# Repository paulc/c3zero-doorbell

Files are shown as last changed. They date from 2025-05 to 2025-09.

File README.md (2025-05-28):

ESP32C3-Zero Doorbell Ring Detector (using Hall effect current sensor)

To plot raw samples (set SAMPLES & SAMPLE_RATE in examples/sample_timer.rs)

```
cargo run --release --example sample_timer | uv run --with matplotlib python plot.py
cargo run --release --example sample_continuous | uv run --with matplotlib python plot.py
```

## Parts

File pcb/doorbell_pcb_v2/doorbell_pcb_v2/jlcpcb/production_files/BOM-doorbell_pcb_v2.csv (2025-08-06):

Comment | Designator | Footprint | LCSC | Quantity
DF06S | D1 | Diode_Bridge_OnSemi_SDIP-4L | C105154 | 1
470nF | C4 | C_0805_2012Metric_Pad1.18x1.45mm_HandSolder | C13967 | 1
470R | R1,R2,R3 | R_0805_2012Metric_Pad1.20x1.40mm_HandSolder | C17710 | 3
MST22D18G2 125 | SW1 | SW-SMD_MST22D18G2 | C2906280 | 1
ACS712xLCTR-05B | U1 | SOIC-8_3.9x4.9mm_P1.27mm | C44471 | 1
1nF | C1 | C_0805_2012Metric_Pad1.18x1.45mm_HandSolder | C46653 | 1
100nF | C2,C5 | C_0805_2012Metric_Pad1.18x1.45mm_HandSolder | C49678 | 2
470uF | C3 | CP_Elec_10x10.5 | C5162362 | 1
LM78M05_TO252 | U2 | TO-252-2 | C58069 | 1
LED | D2 | LED_0805_2012Metric_Pad1.15x1.40mm_HandSolder | C84256 | 1
B5819 | D3 | D_SOD-123 | C8598 | 1
Conn_01x03_Pin |  | PinHeader_1x03_P2.54mm_Vertical |  | 0
TestPoint (ADC In) | TP1 | TestPoint_THTPad_1.5x1.5mm_Drill0.7mm |  | 1

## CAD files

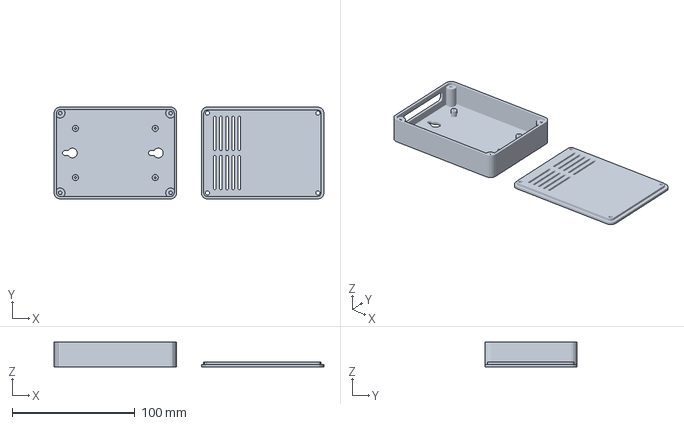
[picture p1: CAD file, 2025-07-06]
case/doorbell_case.3mf
220.0 x 75.0 x 20.0 mm

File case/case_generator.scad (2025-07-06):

// Box Parameters
box_length = 100;
box_width = 75;
box_height = 20;
wall_thickness = 2;
corner_radius = 5;
lid_clearance = 0.2;
lid_height = 2;

// Screw pillar parameters
screw_hole_diameter = 3;
pillar_diameter = 8;
pillar_height = box_height - wall_thickness;

// Mounting hole parameters
mounting_holes = true;
mounting_hole_offset = 0.15;
mounting_top_diameter = 5;
mounting_screw_diameter = 2.5;

// PCB mount parameters
pcb_pillars = true;
pcb_width = 40;     // Between mounting holes
pcb_length = 60;    // Between mounting holes
pcb_pillar_height = 5;
pcb_pillar_diameter = 5;
pcb_hole_diameter = 1.5;

// Cutouts
front_cutout = false;
front_cutout_size = [5,5];
front_cutout_offset = [0,0];
front_cutout_radius = 2.5;

back_cutout = false;
back_cutout_size = [5,5];
back_cutout_offset = [0,0];
back_cutout_radius = 2.5;

left_cutout = false;
left_cutout_size = [5,5];
left_cutout_offset = [0,0];
left_cutout_radius = 2.5;

right_cutout = false;
right_cutout_size = [5,5];
right_cutout_offset = [0,0];
right_cutout_radius = 2.5;

ventilation_holes = false;
num_ventilation_holes = 5;

// Main box with flat top and bottom and screw pillars
module rounded_box(length, width, height, radius, thickness) {
    difference() {
        union() {
            difference() {
                // Outer shape with rounded sides but flat top/bottom
                linear_extrude(height)
                offset(r = radius) offset(delta = -radius)
                square([length, width], center = false);
         
                // Inner cutout
                translate([thickness, thickness, thickness])
                linear_extrude(height - thickness + 0.1)
                offset(r = max(radius - thickness, 0)) 
                offset(delta = -(max(radius - thickness, 0)))
                square([length - thickness*2, width - thickness*2], center = false);
                
                
            }
            // Add four screw pillars
            for (pos = [
                [radius, radius, 0],
                [length - radius, radius, 0],
                [radius, width - radius, 0],
                [length - radius, width - radius, 0]
            ]) {
                translate(pos)
                cylinder(h = pillar_height, d = pillar_diameter, $fn = 20);
            }
            // PCB Pillars
            if (pcb_pillars) {
                pcb_pillars();  
            }
        }
        // Screw holes through pillars
        for (pos = [
            [radius, radius, wall_thickness],
            [length - radius, radius, wall_thickness],
            [radius, width - radius, wall_thickness],
            [length - radius, width - radius, wall_thickness]
        ]) {
            translate(pos)
            cylinder(h = pillar_height + 0.1, d = screw_hole_diameter, $fn = 20);
        }

        // Mounting holes
        if (mounting_holes) {
            mounting_hole(box_length * mounting_hole_offset, box_width/2);
            mounting_hole(box_length * (1 - mounting_hole_offset), box_width/2);
        }
        
        // Cutout
        if (front_cutout) {
                side_cutout("front", 
                    size = front_cutout_size, 
                    offset = front_cutout_offset,
                    radius = front_cutout_radius);
        } 
        if (back_cutout) {
                side_cutout("back", 
                    size = back_cutout_size, 
                    offset = back_cutout_offset,
                    radius = back_cutout_radius);
        } 
        if (left_cutout) {
                side_cutout("left", 
                    size = left_cutout_size, 
                    offset = left_cutout_offset,
                    radius = left_cutout_radius);
        } 
        if (right_cutout) {
                side_cutout("right", 
                    size = right_cutout_size, 
                    offset = right_cutout_offset,
                    radius = right_cutout_radius);
        } 
    }
}

module side_cutout(
    side,               // "front", "back", "left", "right"
    size = [5,5],       // width, height
    offset = [0,0],     // left/right, up/down
    radius = 0
) {
    width = size[0];
    height = size[1];
    
    // Make sure radius is less than width/height
    radius = (radius < min(width/2,height/2)) ? radius : min(width/2,height/2) - 0.01;
    
    lr = offset[0];
    ud = offset[1];
    
    if (side == "front") {
        translate([0 - 0.01, box_width/2 - width / 2 + lr, box_height/2 - height/2 + ud])
            rotate([90,0,90])
            linear_extrude(height = wall_thickness + 0.02, $fn = 20)
                offset (r = radius) offset(delta = -radius)
                square([width,height]);
    } else if (side == "back") {
         translate([box_length - wall_thickness - 0.01, box_width/2 - width/2 + lr, box_height/2 - height/2 + ud])
            rotate([90,0,90])
            linear_extrude(height = wall_thickness + 0.02, $fn = 20)
                offset (r = radius) offset(delta = -radius)
                square([width,height]);   
    } else if (side == "left") {
         translate([box_length/2 - width/2 + lr, wall_thickness + 0.01, box_height/2 - height/2 + ud])
            rotate([90,0,0])
            linear_extrude(height = wall_thickness + 0.02, $fn = 20)
                offset (r = radius) offset(delta = -radius)
                square([width,height]);   
    } else if (side == "right") {
         translate([box_length/2 - width/2 + lr, box_width + 0.01, box_height/2 - height/2 + ud])
            rotate([90,0,0])
            linear_extrude(height = wall_thickness + 0.02, $fn = 20)
                offset (r = radius) offset(delta = -radius)
                square([width,height]);   
    }
}


module pcb_pillars() {
    y0 = (box_width - pcb_width) / 2;
    y1 = y0 + pcb_width;
    x0 = (box_length - pcb_length) / 2;
    x1 = x0 + pcb_length;
    
    for (pos = [[x0,y0,0],[x0,y1,0],[x1,y0,0],[x1,y1,0]]) {
        translate(pos) 
        difference() {
            cylinder(h = pcb_pillar_height + wall_thickness, d = pcb_pillar_diameter, $fn = 20);
            translate([0,0,wall_thickness])
                cylinder(h = pcb_pillar_height + 0.01, d = pcb_hole_diameter, $fn = 20);
        }
    }
}

module mounting_hole(x,y) {
        // We add a very small +/- z delta to make preview render clearer
        translate([x,y,-0.01])
            linear_extrude(wall_thickness + 0.02)
                rotate([0,0,180])
                union() {
                    circle(d = mounting_top_diameter, $fn=20);
                    translate([mounting_top_diameter/2,0,0])
                        offset(r = mounting_screw_diameter/2, $fn = 20) 
                            square([mounting_screw_diameter,0.1], center= true);
                }
}

// Lid with flat bottom and screw holes
module rounded_lid(length, width, height, radius, thickness) {
    difference() {
        union() {
            // Main lid plate with flat bottom
            linear_extrude(height)
            offset(r = radius) offset(delta = -radius)
            square([length, width], center = false);
            
            // Lip that fits inside the box
            translate([thickness, thickness, height])
            linear_extrude(height)
            offset(r = max(radius - thickness - lid_clearance, 0))
            offset(delta = -(max(radius - thickness - lid_clearance, 0)))
            square([
                length - thickness*2 - lid_clearance*2, 
                width - thickness*2 - lid_clearance*2
            ], center = false);
        }
        
        // Screw holes in lid
        for (pos = [
            [radius, radius, 0],
            [length - radius, radius, 0],
            [radius, width - radius, 0],
            [length - radius, width - radius, 0]
        ]) {
            translate(pos)
            cylinder(h = height*2, d = screw_hole_diameter + 0.5, $fn = 10); // Slightly larger for clearance
        }
        
        // Ventilation holes
        if (ventilation_holes) {
            for (i = [0:num_ventilation_holes-1] ) {
                translate([length * (0.1 + i/20), width * 0.1, -0.01])
                    linear_extrude(height * 2 + 0.02)
                        offset(r = thickness/2, $fn = 10) offset(delta = -thickness/2)
                        square([height + 0.01, width * 0.375]);
                translate([length * (0.1 + i/20), width * 0.525, -0.01])
                    linear_extrude(height * 2 + 0.02)
                        offset(r = thickness/2, $fn = 10) offset(delta = -thickness/2)
                        square([height + 0.01, width * 0.375]);
            }    
        }
    }
}

// Create the box
rounded_box(box_length, box_width, box_height, corner_radius, wall_thickness);

// Create the lid (positioned next to the box for printing)
translate([box_length + 20, 0, 0])
    rounded_lid(box_length, box_width, lid_height, corner_radius, wall_thickness);

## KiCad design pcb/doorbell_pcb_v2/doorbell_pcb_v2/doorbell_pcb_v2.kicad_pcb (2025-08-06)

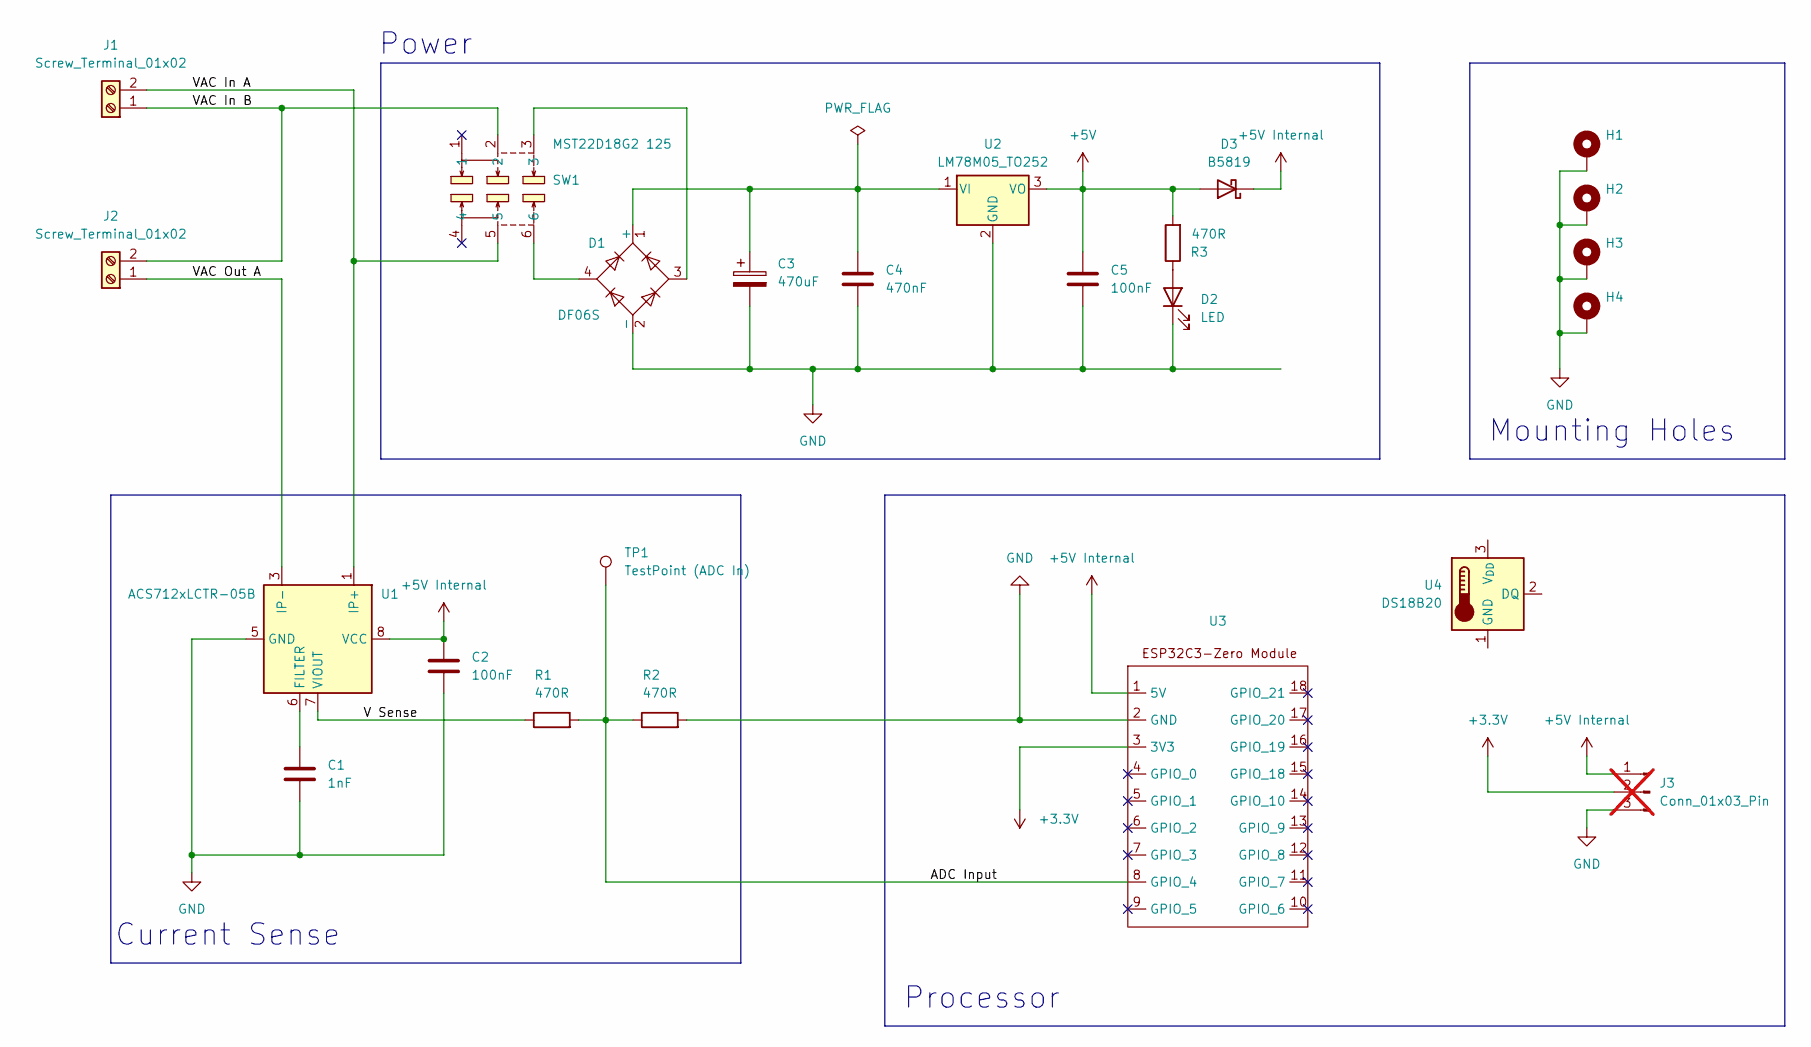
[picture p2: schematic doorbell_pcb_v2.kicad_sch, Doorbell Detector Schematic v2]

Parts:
C1: 1nF; C_0805_2012Metric_Pad1.18x1.45mm_HandSolder; LCSC C46653
C2, C5: 100nF; C_0805_2012Metric_Pad1.18x1.45mm_HandSolder; LCSC C49678
C3: 470uF; CP_Elec_10x10.5; LCSC C5162362
C4: 470nF; C_0805_2012Metric_Pad1.18x1.45mm_HandSolder; LCSC C13967
D1: DF06S; Diode_Bridge_OnSemi_SDIP-4L; LCSC C105154
D2: LED; LED_0805_2012Metric_Pad1.15x1.40mm_HandSolder; JLCPCB C84256
D3: B5819; D_SOD-123; LCSC C8598
H1, H2, H3, H4: MountingHole_Pad; MountingHole_2.2mm_M2_Pad
J1: Screw_Terminal_01x02; CONN-TH_P5.00_KF301-5.0-2P; LCSC C474881
J2: Screw_Terminal_01x02; CONN-TH_P5.00_KF301-5.0-2P; JLC C474881
J3: Conn_01x03_Pin; PinHeader_1x03_P2.54mm_Vertical; not fitted
R1, R2, R3: 470R; R_0805_2012Metric_Pad1.20x1.40mm_HandSolder; LCSC C17710
SW1: MST22D18G2 125; SW-SMD_MST22D18G2; LCSC Part C2906280
TP1: TestPoint (ADC In); TestPoint_THTPad_1.5x1.5mm_Drill0.7mm
U1: ACS712xLCTR-05B; SOIC-8_3.9x4.9mm_P1.27mm; LCSC C44471
U2: LM78M05_TO252; TO-252-2; LCSC C58069
U3: esp32c3-zero
U4: DS18B20; TO-92

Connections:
+3.3V: J3.2, U3.3 (3V3)
+5V: C5.1, D3.2 (A), R3.2, U2.3 (VO)
+5V Internal: C2.1, D3.1 (K), J3.1, U1.8 (VCC), U3.1 (5V)
/ADC Input: R1.2, R2.1, TP1.1, U3.8 (GPIO_4)
/V Sense: R1.1, U1.7 (VIOUT)
/VAC In A: J1.2, SW1.5, U1.1 (IP+), U1.2 (IP+)
/VAC In B: J1.1, J2.2, SW1.2
/VAC Out A: J2.1, U1.3 (IP-), U1.4 (IP-)
GND: C1.2, C2.2, C3.2, C4.2, C5.2, D1.2 (-), D2.1 (K), H1.1, H2.1, H3.1, H4.1, J3.3, R2.2, U1.5 (GND), U2.2 (GND), U3.2 (GND)
unnamed: C3.1, C4.1, D1.1 (+), U2.1 (VI)
unnamed: D1.3, SW1.3
unnamed: D1.4, SW1.6
unnamed: D2.2 (A), R3.1
unnamed: C1.1, U1.6 (FILTER)

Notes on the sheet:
Processor
Current Sense
Mounting Holes
Power

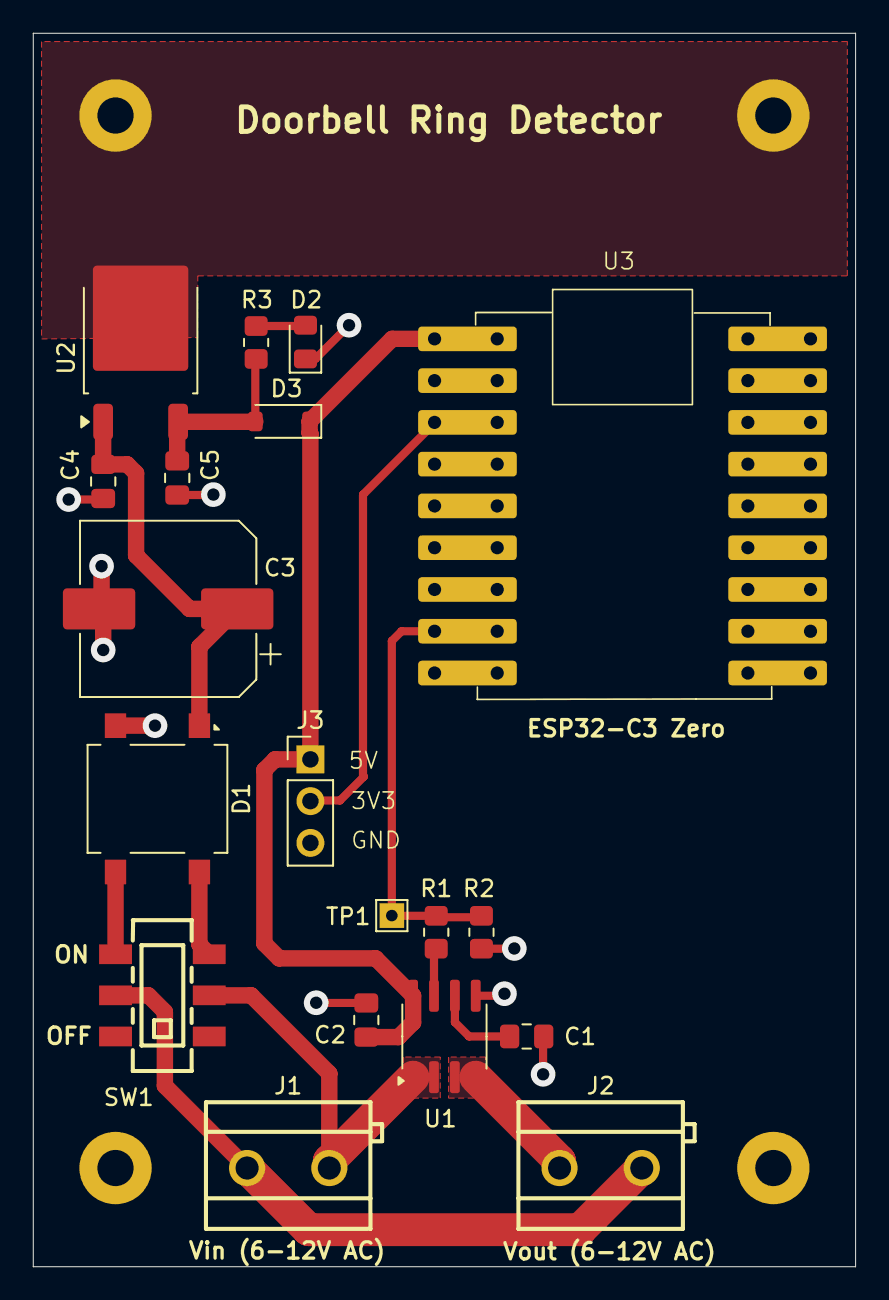
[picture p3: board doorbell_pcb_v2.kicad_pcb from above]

Board: 2 copper layers, 50.0 x 75.0 mm, 23 parts (0 on the bottom side), 14 nets.

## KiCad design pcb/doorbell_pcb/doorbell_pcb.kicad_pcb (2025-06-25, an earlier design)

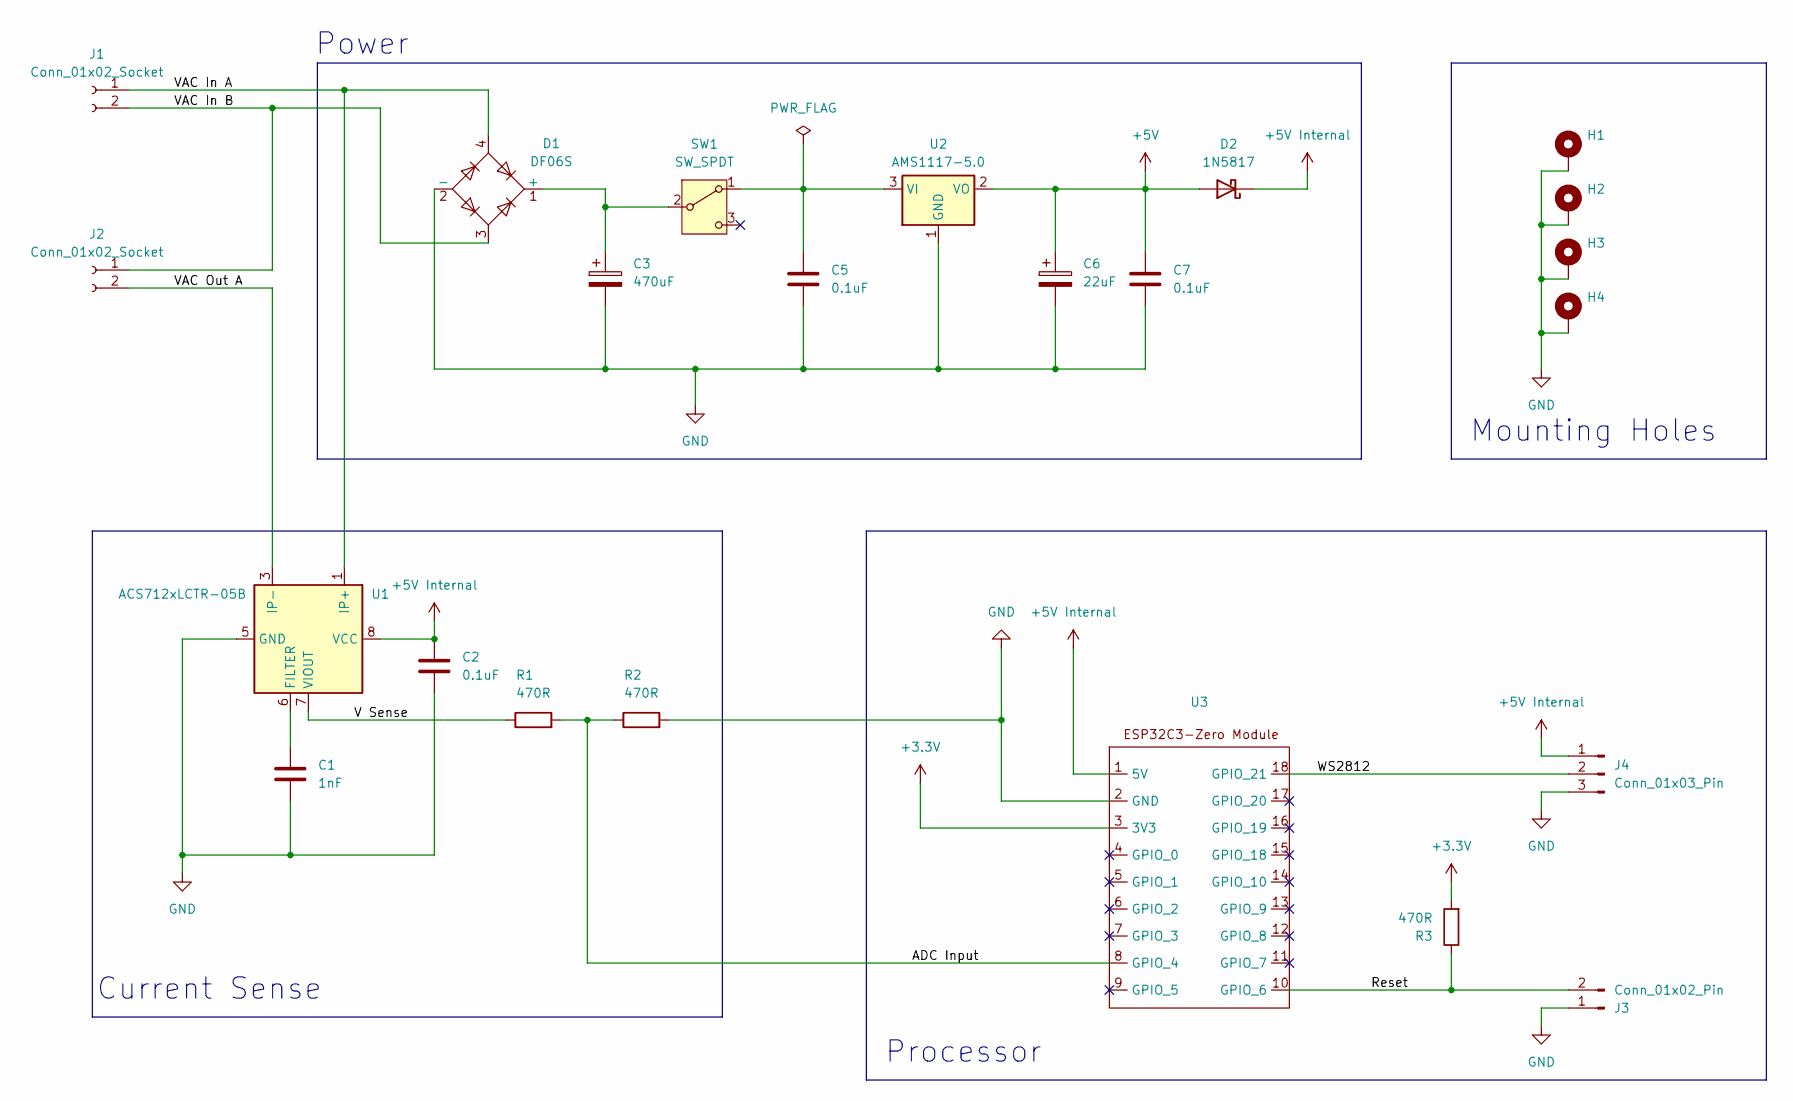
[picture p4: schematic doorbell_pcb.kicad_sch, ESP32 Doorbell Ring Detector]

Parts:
C1: 1nF; C_0805_2012Metric
C2, C5, C7: 0.1uF; C_0805_2012Metric
C3: 470uF; CP_Elec_10x10.5
C6: 22uF; CP_Elec_10x10.5
D1: DF06S; Diode_Bridge_OnSemi_SDIP-4L
D2: 1N5817; D_SOD-323
H1, H2, H3, H4: MountingHole_Pad; MountingHole_2.2mm_M2_Pad
J1, J2: Conn_01x02_Socket; TerminalBlock_Phoenix_MPT-0,5-2-2.54_1x02_P2.54mm_Horizontal
J3: Conn_01x02_Pin; JST_EH_B2B-EH-A_1x02_P2.50mm_Vertical
J4: Conn_01x03_Pin; JST_EH_B3B-EH-A_1x03_P2.50mm_Vertical
R1, R2, R3: 470R; R_0805_2012Metric
SW1: SW_SPDT; SW_SPDT_CK_JS102011SAQN
U1: ACS712xLCTR-05B; SOIC-8_3.9x4.9mm_P1.27mm
U2: AMS1117-5.0; SOT-223-3_TabPin2
U3: esp32c3-zero

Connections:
+3.3V: R3.2, U3.3 (3V3)
+5V: C6.1, C7.1, D2.2 (A), U2.2 (VO)
+5V Internal: C2.1, D2.1 (K), J4.1, U1.8 (VCC), U3.1 (5V)
/ADC Input: R1.2, R2.1, U3.8 (GPIO_4)
/Reset: J3.2, R3.1, U3.10 (GPIO_6)
/V Sense: R1.1, U1.7 (VIOUT)
/VAC In A: D1.4, J1.1, U1.1 (IP+), U1.2 (IP+)
/VAC In B: D1.3, J1.2, J2.1
/VAC Out A: J2.2, U1.3 (IP-), U1.4 (IP-)
/WS2812: J4.2, U3.18 (GPIO_21)
GND: C1.2, C2.2, C3.2, C5.2, C6.2, C7.2, D1.2 (-), H1.1, H2.1, H3.1, H4.1, J3.1, J4.3, R2.2, U1.5 (GND), U2.1 (GND), U3.2 (GND)
unnamed: C3.1, D1.1 (+), SW1.2 (B)
unnamed: C5.1, SW1.1 (A), U2.3 (VI)
unnamed: C1.1, U1.6 (FILTER)

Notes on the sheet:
Current Sense
Power
Mounting Holes
Processor

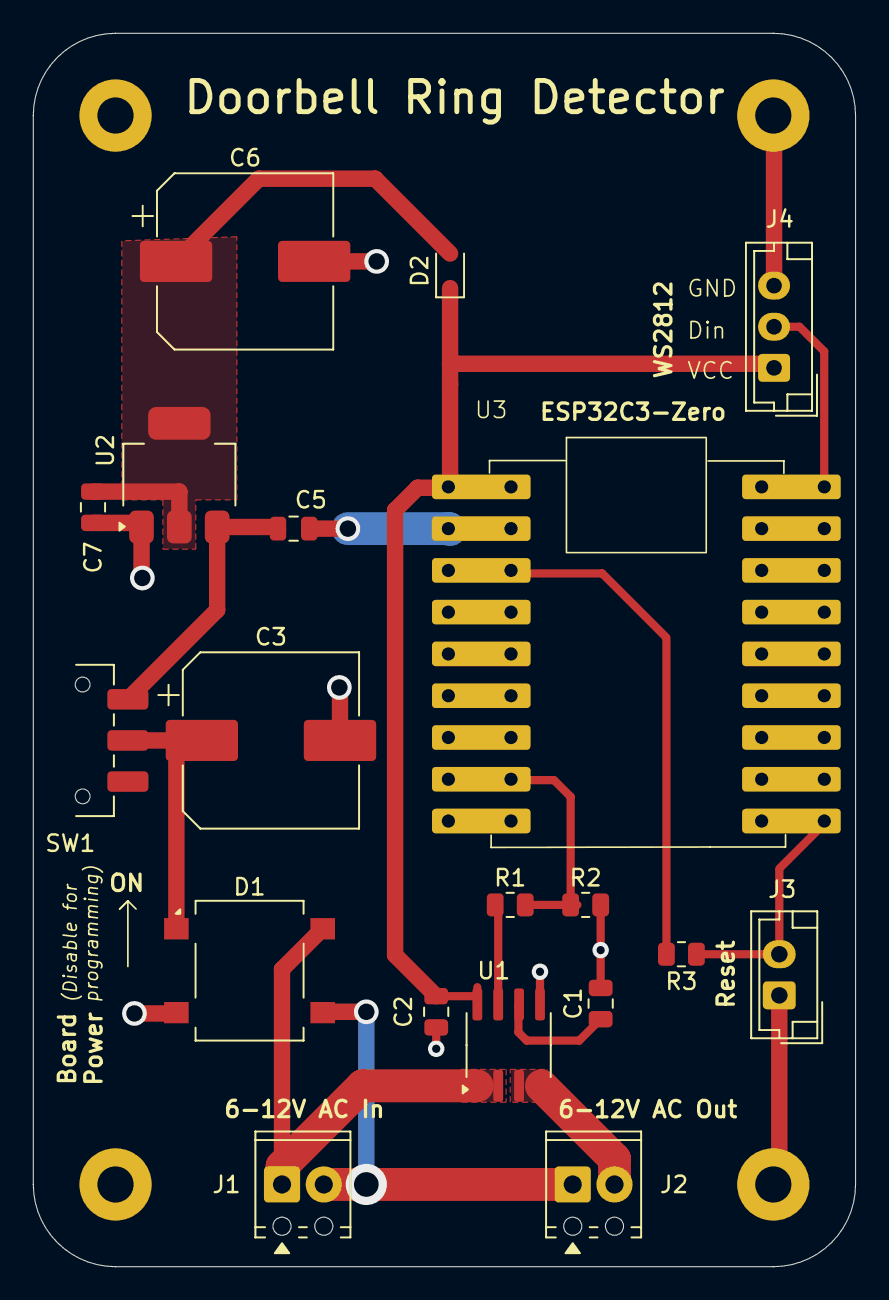
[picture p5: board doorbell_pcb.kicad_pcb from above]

Board: 2 copper layers, 50.0 x 75.0 mm, 23 parts (0 on the bottom side), 14 nets.

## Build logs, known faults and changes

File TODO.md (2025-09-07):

[ ] Convert MQTT/Pushover/Wifi forms to application/json
[ ] Add config test to MQTT/Pushover forms
[ ] Sync mqtt alarm code with doorbell
[ ] Add config option for LED flash
[ ] MQTT alarm PWM ringer
[ ] Add config option for ADC gain
[ ] Move doorbell/alarm to src/bin
[ ] Add temperature sensor?
[ ] Convert status messages to JSON

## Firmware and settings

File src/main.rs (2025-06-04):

use esp_idf_hal::gpio::{OutputPin, PinDriver};
use esp_idf_hal::peripherals::Peripherals;
use esp_idf_hal::task::watchdog::{TWDTConfig, TWDTDriver};
use esp_idf_svc::eventloop::EspSystemEventLoop;
use esp_idf_svc::nvs::EspDefaultNvsPartition;
use esp_idf_svc::wifi::EspWifi;

use std::sync::mpsc;
use std::thread;
use std::time::Duration;

use doorbell::httpd;
use doorbell::nvs;
use doorbell::rgb;
use doorbell::wifi;
use doorbell::ws2812;

mod adc;
mod alert;
mod stats;

fn main() -> anyhow::Result<()> {
    esp_idf_hal::sys::link_patches();

    // Bind the log crate to the ESP Logging facilities
    esp_idf_svc::log::EspLogger::initialize_default();
    log::info!("Started...");

    // Initialise peripherals
    let peripherals = Peripherals::take()?;
    let sys_loop = EspSystemEventLoop::take()?;
    let nvs_default_partition = EspDefaultNvsPartition::take()?;

    // Hardware Watchdog
    let twdt_config = TWDTConfig {
        duration: Duration::from_secs(2),
        panic_on_trigger: true,
        subscribed_idle_tasks: enumset::enum_set!(esp_idf_hal::cpu::Core::Core0),
    };
    let mut twdt_driver = TWDTDriver::new(peripherals.twdt, &twdt_config)?;

    // Status display (C3-Zero onboard WS2812 LED pin = GPIO10)
    let ws2812 = peripherals.pins.gpio10.downgrade_output();
    let channel = peripherals.rmt.channel0;
    let mut status = ws2812::Ws2812RmtSingle::new(ws2812, channel, rgb::RgbLayout::Rgb)?;
    status.set(rgb::OFF)?;

    // Ring led
    let mut ring_led = PinDriver::output(peripherals.pins.gpio6)?;
    ring_led.set_high()?;

    // Initislise NVStore
    nvs::NVStore::init(nvs_default_partition.clone(), "DOORBELL")?;

    // Initialise WiFi
    let mut wifi: EspWifi<'_> = EspWifi::new(
        peripherals.modem,
        sys_loop.clone(),
        Some(nvs_default_partition.clone()),
    )?;
    wifi::wifi_init(&mut wifi)?;

    // Initial scan
    wifi::wifi_scan(&mut wifi)?;

    let mut wifi_config: Option<wifi::APConfig> = None;

    for config in wifi::find_known_aps() {
        log::info!("Trying network: {}", config.ssid);
        match wifi::connect_wifi(&mut wifi, &config, 10000) {
            Ok(true) => {
                log::info!("Connected to Wifi: {}", config.ssid);
                wifi_config = Some(config);
                break;
            }
            Ok(false) => {
                log::info!("Failed to connect to Wifi: {}", config.ssid);
            }
            Err(e) => {
                log::info!("Wifi Error: {} [{}]", config.ssid, e);
            }
        }
    }

    log::info!("WiFi Config: {wifi_config:?}");

    let mut _server = if let Some(config) = wifi_config {
        log::info!("Connected to SSID: {}", config.ssid);
        log::info!("IP: {}", wifi.sta_netif().get_ip_info()?.ip);
        httpd::start_http_server()?
    } else {
        log::info!("No valid config found - starting AP");
        wifi::start_access_point(&mut wifi)?;
        log::info!("AP Mode - {:?}", wifi.ap_netif());
        httpd::start_http_server()?
    };

    // ADC Channel
    let (adc_tx, adc_rx) = mpsc::channel();

    // Need to expand stack size as we allocate ADC & FP buffers on stack
    let adc_task = thread::Builder::new()
        .stack_size(8192)
        .spawn(move || {
            adc::adc_task(
                peripherals.timer00,
                peripherals.adc1,
                peripherals.pins.gpio4,
                adc_tx,
                false,
            )
        })
        .expect("Error starting adc_task:");

    // Alert Channel
    let (alert_tx, alert_rx) = mpsc::channel();

    let alert_task = thread::Builder::new()
        .stack_size(8192)
        .spawn(move || alert::alert_task(alert_rx))
        .expect("Error starting alert_task:");

    // Dont configure watchdog until we have setup background tasks
    let mut watchdog = twdt_driver.watch_current_task()?;

    loop {
        // Check tasks still running - restart if not
        if adc_task.is_finished() || alert_task.is_finished() {
            log::error!("Task Failed - Restarting");
            esp_idf_hal::reset::restart();
        }
        match adc_rx.recv_timeout(Duration::from_millis(500)) {
            Ok(msg) => match msg {
                adc::RingMessage::RingStart => {
                    log::info!("adc_rx :: {msg:?}");
                    ring_led.set_low()?;
                    alert_tx.send(alert::AlertMessage::RingStart)?;
                }
                adc::RingMessage::RingStop => {
                    log::info!("adc_rx :: {msg:?}");
                    ring_led.set_high()?;
                    alert_tx.send(alert::AlertMessage::RingStop)?;
                }
                adc::RingMessage::Stats(s) => {
                    log::info!(
                        "[{}/{:06}] Mean: {:.4} :: Std Dev: {:.4}/{:.4} :: Ring: {}",
                        s.count,
                        s.elapsed,
                        s.mean,
                        s.stddev,
                        s.threshold,
                        s.ring
                    );
                }
            },
            Err(mpsc::RecvTimeoutError::Timeout) => {
                log::info!("adc_rx :: tick");
                status.set(rgb::BLUE)?;
                status.set(rgb::OFF)?;
            }
            Err(e) => log::error!("ERROR :: adc_rx :: {e:?}"),
        }
        watchdog.feed()?
    }
}

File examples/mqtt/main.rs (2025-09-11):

#![feature(lock_value_accessors)]

use esp_idf_hal::gpio::OutputPin;
use esp_idf_hal::task::watchdog::{TWDTConfig, TWDTDriver};
use esp_idf_svc::eventloop::EspSystemEventLoop;
use esp_idf_svc::hal::ledc;
use esp_idf_svc::hal::prelude::*;
use esp_idf_svc::http::Method;
use esp_idf_svc::nvs::EspDefaultNvsPartition;
use esp_idf_svc::wifi::EspWifi;

use std::sync::mpsc;
use std::thread;
use std::time::Duration;

use doorbell::nvs::NVStore;
use doorbell::ota::Ota;
use doorbell::web::{BuildInfo, HomePage, NavBar, NavLink, WebServer};
use doorbell::wifi::{APConfig, APStore, WifiManager, WifiState};
use doorbell::ws2812::{colour, RgbLayout, Ws2812RmtSingle};

mod led_task;
mod mqtt_task;
mod pwm_task;

const AP_SSID: &str = "ESP32C3-AP";
const AP_PASSWORD: &str = "password";

const NVS_NAMESPACE: &str = "DOORBELL";

const WATCHDOG_TIMEOUT: u64 = 60;

const BUILD_INFO: BuildInfo = BuildInfo {
    build_ts: env!("BUILD_TS"),
    build_branch: env!("BUILD_BRANCH"),
    build_hash: env!("BUILD_HASH"),
    build_profile: env!("BUILD_PROFILE"),
};

// Static NavBar
pub const NAVBAR: NavBar = NavBar {
    title: "MQTT Alarm",
    links: &[
        NavLink {
            url: "/wifi",
            label: "Wifi Configuration",
        },
        NavLink {
            url: "/mqtt",
            label: "MQTT Configuration",
        },
        NavLink {
            url: "/ota_page",
            label: "OTA Update",
        },
        NavLink {
            url: "/reset_page",
            label: "Reset",
        },
    ],
};

fn main() -> anyhow::Result<()> {
    // It is necessary to call this function once. Otherwise some patches to the runtime
    // implemented by esp-idf-sys might not link properly. See https://github.com/esp-rs/esp-idf-template/issues/71
    esp_idf_svc::sys::link_patches();

    // Bind the log crate to the ESP Logging facilities
    esp_idf_svc::log::EspLogger::initialize_default();
    log::info!("Starting...");

    // Initialise peripherals
    let peripherals = Peripherals::take()?;
    let sys_loop = EspSystemEventLoop::take()?;
    let nvs_default_partition = EspDefaultNvsPartition::take()?;

    // Hardware Watchdog
    let twdt_config = TWDTConfig {
        duration: Duration::from_secs(WATCHDOG_TIMEOUT),
        panic_on_trigger: true,
        subscribed_idle_tasks: enumset::enum_set!(esp_idf_hal::cpu::Core::Core0),
    };
    let mut twdt_driver = TWDTDriver::new(peripherals.twdt, &twdt_config)?;

    // NVStore
    let nvs = NVStore::init(nvs_default_partition.clone(), NVS_NAMESPACE)?;

    // WiFi
    let mut wifi = WifiManager::new(EspWifi::new(
        peripherals.modem,
        sys_loop.clone(),
        Some(nvs_default_partition.clone()),
    )?)?;

    let mut wifi_state = WifiState::NotConnected;

    // Onboard WS2812 (GPIO10)
    let ws2812 = peripherals.pins.gpio10.downgrade_output();
    let channel = peripherals.rmt.channel0;
    let mut led = Ws2812RmtSingle::new(ws2812, channel, RgbLayout::Grb)?;
    led.set(colour::OFF)?;

    // LED task
    let (led_tx, led_rx) = mpsc::channel::<led_task::LedMessage>();
    let _led_task = thread::spawn(move || led_task::led_task(led, led_rx));

    // PWM task
    let timer_config = ledc::config::TimerConfig::default()
        .frequency(440.into())
        .resolution(ledc::Resolution::Bits14);
    let (pwm_tx, pwm_rx) = mpsc::channel::<pwm_task::PwmMessage>();
    let _pwm_task = thread::spawn(move || {
        pwm_task::pwm_task(
            peripherals.pins.gpio6.downgrade_output(),
            peripherals.ledc.timer0,
            peripherals.ledc.channel0,
            timer_config,
            pwm_rx,
        )
    });
    pwm_tx.send(pwm_task::PwmMessage::SetDuty(0.5))?;
    pwm_tx.send(pwm_task::PwmMessage::Enable)?;

    // Start web server
    let mut web = WebServer::new(NAVBAR)?;

    // OTA
    let ota = Ota::new();

    // Add module handlers
    nvs.add_handlers(&mut web, NAVBAR)?;
    wifi.add_handlers(&mut web, NAVBAR)?;
    ota.add_handlers(&mut web, NAVBAR)?;

    // Home Page
    let home_page = HomePage::new(NAVBAR.title, BUILD_INFO.display_fields(), NAVBAR);
    home_page.set_status(wifi_state.display_fields())?;
    web.add_handler("/", Method::Get, home_page.make_handler())?;

    let mqtt = mqtt_task::MQTTTask::init()?;
    mqtt.add_handlers(&mut web, NAVBAR)?;

    // Start watchdog after initialisation
    let mut watchdog = twdt_driver.watch_current_task()?;
    let mut count = 0_usize;
    let mut mqtt_started = false;

    let mut prev_state = (wifi_state.clone(), false, false);
    let mut freq = 100_u32;

    loop {
        let current_state = (wifi_state.clone(), wifi.is_connected()?, mqtt_started);
        if current_state != prev_state {
            // State Changed
            log::info!(
                "STATE: {}, connected: {}, mqtt: {}",
                current_state.0,
                current_state.1,
                current_state.2
            );
        }

        match current_state {
            (WifiState::NotConnected, _, _) => {
                // NotConnected - try to connect to known AP (or start local AP)
                wifi.scan()?;
                wifi_state = wifi.try_connect(
                    &APStore::get_aps()?,
                    Some(APConfig::new(AP_SSID, AP_PASSWORD)?),
                    20_000,
                )?;
                log::info!("WifiState: {wifi_state:?}");
                // Update home page status
                home_page.set_status(wifi_state.display_fields())?;
            }
            (WifiState::Station(ref ap, _), false, _) => {
                // WiFi disconnected - try to reconnect (every 30 secs)
                if count.is_multiple_of(30) {
                    log::error!("WIFi Disconnected: Attempting to reconnect");
                    match wifi.connect_sta(ap, 30000) {
                        Ok(WifiState::Station(config, ip_info)) => {
                            log::info!("WIFi Reconnected: {wifi_state}");
                            wifi_state = WifiState::Station(config, ip_info);
                            // Update home page status
                            home_page.set_status(wifi_state.display_fields())?;
                        }
                        Ok(_) => {
                            log::info!("WiFi Failed to Reconnect");
                        }
                        Err(e) => {
                            // Something went wrong - possibly reboot?
                            log::info!("WiFi Error Reconnecting: {e}");
                        }
                    }
                }
            }
            (WifiState::Station(_, _), true, false) => {
                // WiFi connected - start mqtt_task
                /*
                if mqtt.is_enabled() {
                    let led_tx = led_tx.clone();
                    let pwm_tx = pwm_tx.clone();
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

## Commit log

2025-05-24 Use timer/notification for ADC timing
    [samples.csv]
2025-05-28 Continuous ADC driver
2025-05-30 Fix ADC reset bug & add ring webhook
    [main.rs]
2025-06-03 Move ADC/Alert to tasks
2025-06-04 Check adc/alert tasks still running
2025-06-20 Add button_task
2025-06-21 Add button task
2025-06-21 Add button_closure
2025-06-21 Add PCB/Case
    [BOM-Doorbell (Smaller).csv, case_generator.scad, doorbell_case.3mf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]
2025-06-25 Update reset_page to use AbortController
    [doorbell_pcb.kicad_pcb]
2025-07-03 Add MQTT error retry
    [main.rs]
2025-07-03 Switch to mqtt_chan handler
2025-07-14 Initial OTA Support
    [partitions.csv]
2025-07-15 OTA updates
    [partitions.csv]
2025-07-21 Refactor adc_task (probably need to revert)
    [adc.rs, main.rs]
2025-07-26 ADC waveform display
2025-07-27 Add ADC stats display
2025-07-28 Configurable ADC threshold
2025-07-28 Updated PCB
    [BOM-doorbell_pcb_v2.csv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]
2025-08-05 Watchdog wrapper - avoid problem with subscription being droped if app_main exits
    [main.rs, mqtt.rs]
2025-08-06 PCB updates
    [BOM-doorbell_pcb_v2.csv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]
2025-09-09 Add pwm_task module
2025-09-11 PWM set_frequency
